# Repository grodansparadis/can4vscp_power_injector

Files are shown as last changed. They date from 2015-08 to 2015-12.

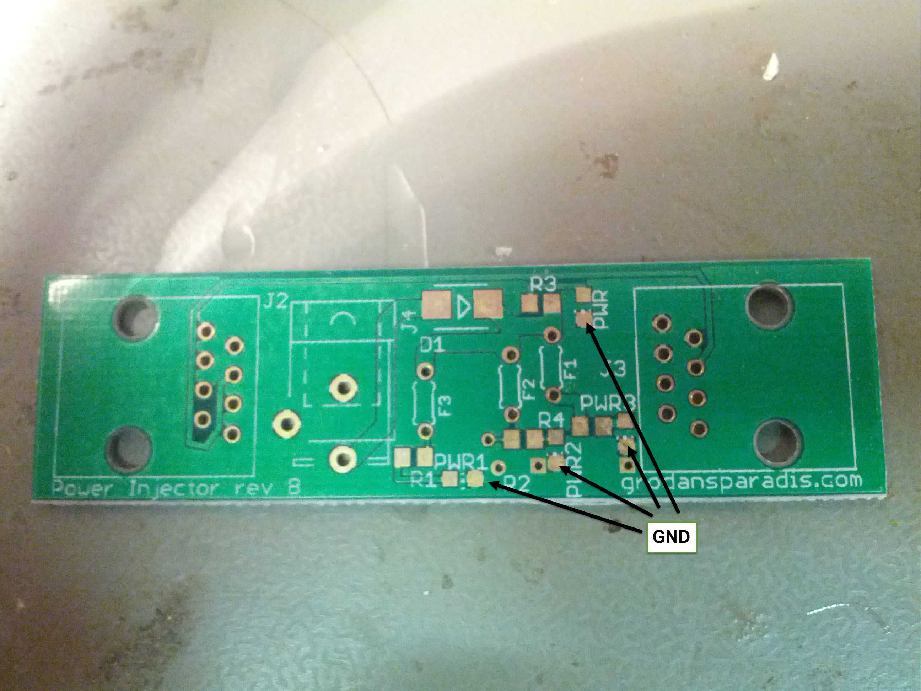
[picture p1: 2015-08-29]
docs/markers_gnd.jpg

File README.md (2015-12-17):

<h1>Power injector module for CAN4VSCP</h1>



With the power injector you can power the CAN4VSCP bus and also power up to 16 CAN4VSCP modules using the daisy chain connector. This is a perfect companion board to use when you need to connect a number of CAN4VSCP boards in a cabinet and then connect them to thw world.

It also have two 120 ohm terminations that can be activated if needed.

It is also possible to get the module with a resettable fuse that allow a maximum of 500 mA for all modules connected to the board. The fuse will trip at about 800 mA. This can be a good safety precaution for wired networks. 

<hr>

This project is part of the <a href="http://www.vscp.org">VSCP (Very Simple Control Protocol) project</a>. 

<hr>

This project is licensed under the 
<a href="http://creativecommons.org/licenses/by-nc-sa/3.0/">Creative Commons open source license Attribution-NonCommercial-ShareAlike 3.0 Unported</a>. 
Other license options are available by conacting <a href="malto:info@grodansparadis.com">Paradis of the Frog AB</a>

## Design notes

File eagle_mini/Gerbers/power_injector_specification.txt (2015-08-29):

Ake Hedman
Grodans Paradis AB

Date:				2014-06-18
Part Number: 		Power Injector
Number of boards: 	120
Number of layers: 	2 
Material: 			FR4
Final Thickness:	1.6 mm
Final copper:		1/1oz
Surface treatment: 	ENIG
Unit Size:			72 x 20 mm
Panel Size:		
Unit/panel:			12
Solder Mask:		Green
Silk Screen: 		White	
Outline Profile:	CNC Routing + V-cut
X-out Allowed:		1
Stencil needed:		no

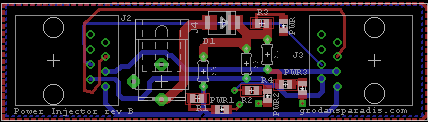
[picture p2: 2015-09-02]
eagle_mini/power_injector_mini_rev_b_brd.png

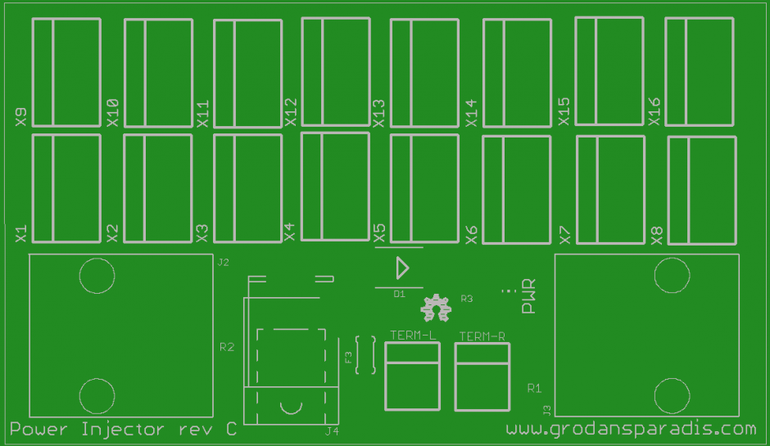
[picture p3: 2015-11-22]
eagle_big/Gerbers/power_injector_rev_c_gto_small.png

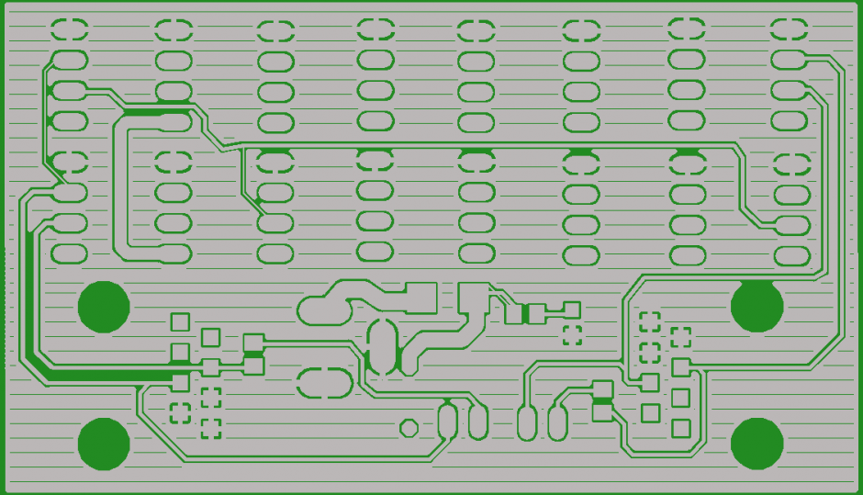
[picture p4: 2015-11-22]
eagle_big/Gerbers/power_injector_rev_c_gtl_small.png

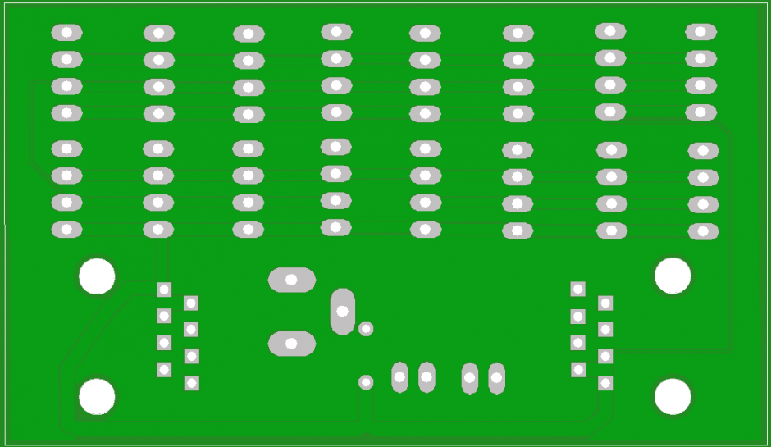
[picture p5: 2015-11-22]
eagle_big/Gerbers/power_injector_rev_c_bottom_small.png

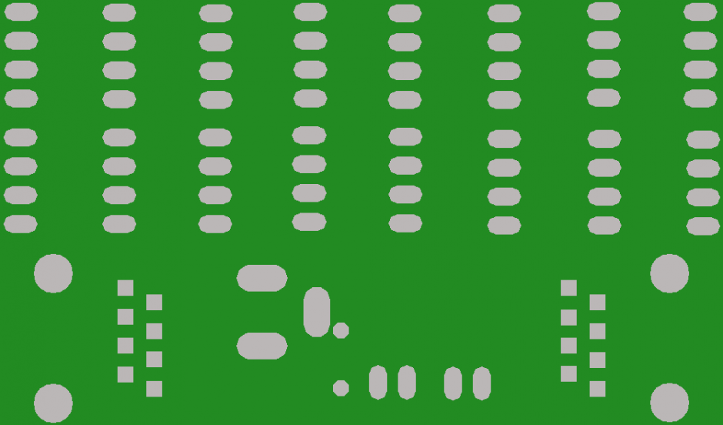
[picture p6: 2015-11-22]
eagle_big/Gerbers/power_injector_rev_c_gbs_small.png

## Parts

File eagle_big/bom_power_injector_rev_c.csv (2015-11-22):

Part | Value | Device | Package | Description | MF | MPN | OC_FARNELL | OC_NEWARK
D1 | PMEG3015EH,115 | DIODE-SMB | SMB | DIODE
F3 | MF-R050 | R-EU_0204/5 | 0204/5 | RESISTOR, European symbol
J2 | A00-108-220-450 | A00-108-220-450 | RJ-45
J3 | A00-108-220-450 | A00-108-220-450 | RJ-45
J4 |  | JACK-PLUG0 | SPC4077 | DC POWER JACK |  |  | unknown | unknown
LED1 |  | LEDCHIP-LED0805 | CHIP-LED0805 | LED
R1 | 120 | R-EU_R0805 | R0805 | RESISTOR, European symbol
R2 | 120 | R-EU_R0805 | R0805 | RESISTOR, European symbol
R3 | 4k7 | R-EU_R0805 | R0805 | RESISTOR, European symbol
TERM-L | 22-23-2021 | 22-23-2021 | 22-23-2021 | .100 (2.54mm) Center Header - 2 Pin" | MOLEX | 22-23-2021 | 1462926 | 25C3832
TERM-R | 22-23-2021 | 22-23-2021 | 22-23-2021 | .100 (2.54mm) Center Header - 2 Pin" | MOLEX | 22-23-2021 | 1462926 | 25C3832
X1 | 22-23-2041 | 22-23-2041 | 22-23-2041 | .100 (2.54mm) Center Header - 4 Pin" | MOLEX | 22-23-2041 | 1462920 | 38C0355
X2 | 22-23-2041 | 22-23-2041 | 22-23-2041 | .100 (2.54mm) Center Header - 4 Pin" | MOLEX | 22-23-2041 | 1462920 | 38C0355
X3 | 22-23-2041 | 22-23-2041 | 22-23-2041 | .100 (2.54mm) Center Header - 4 Pin" | MOLEX | 22-23-2041 | 1462920 | 38C0355
X4 | 22-23-2041 | 22-23-2041 | 22-23-2041 | .100 (2.54mm) Center Header - 4 Pin" | MOLEX | 22-23-2041 | 1462920 | 38C0355
X5 | 22-23-2041 | 22-23-2041 | 22-23-2041 | .100 (2.54mm) Center Header - 4 Pin" | MOLEX | 22-23-2041 | 1462920 | 38C0355
X6 | 22-23-2041 | 22-23-2041 | 22-23-2041 | .100 (2.54mm) Center Header - 4 Pin" | MOLEX | 22-23-2041 | 1462920 | 38C0355
X7 | 22-23-2041 | 22-23-2041 | 22-23-2041 | .100 (2.54mm) Center Header - 4 Pin" | MOLEX | 22-23-2041 | 1462920 | 38C0355
X8 | 22-23-2041 | 22-23-2041 | 22-23-2041 | .100 (2.54mm) Center Header - 4 Pin" | MOLEX | 22-23-2041 | 1462920 | 38C0355
X9 | 22-23-2041 | 22-23-2041 | 22-23-2041 | .100 (2.54mm) Center Header - 4 Pin" | MOLEX | 22-23-2041 | 1462920 | 38C0355
X10 | 22-23-2041 | 22-23-2041 | 22-23-2041 | .100 (2.54mm) Center Header - 4 Pin" | MOLEX | 22-23-2041 | 1462920 | 38C0355
X11 | 22-23-2041 | 22-23-2041 | 22-23-2041 | .100 (2.54mm) Center Header - 4 Pin" | MOLEX | 22-23-2041 | 1462920 | 38C0355
X12 | 22-23-2041 | 22-23-2041 | 22-23-2041 | .100 (2.54mm) Center Header - 4 Pin" | MOLEX | 22-23-2041 | 1462920 | 38C0355
X13 | 22-23-2041 | 22-23-2041 | 22-23-2041 | .100 (2.54mm) Center Header - 4 Pin" | MOLEX | 22-23-2041 | 1462920 | 38C0355
X14 | 22-23-2041 | 22-23-2041 | 22-23-2041 | .100 (2.54mm) Center Header - 4 Pin" | MOLEX | 22-23-2041 | 1462920 | 38C0355
X15 | 22-23-2041 | 22-23-2041 | 22-23-2041 | .100 (2.54mm) Center Header - 4 Pin" | MOLEX | 22-23-2041 | 1462920 | 38C0355
X16 | 22-23-2041 | 22-23-2041 | 22-23-2041 | .100 (2.54mm) Center Header - 4 Pin" | MOLEX | 22-23-2041 | 1462920 | 38C0355

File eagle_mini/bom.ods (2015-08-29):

Partl | ist exported fro | m C:/Users/akhe/Do | cuments/dev | elopment/hardware_zeus/can | 4vscp/power_inje | ctor/eagle/power_injector_r | ev_a.sch at 2011-10-03 | 11:50:20
Part | Value | Device Pa | ckage | Description | Description | Supplier Partnumber | Price
D1 | PMEG3015EH,115 | DIODE-SMB SM | B | DIODE | Protection diod | Digikey 568-4127-1-ND | 3,84
F1 | MF-R050 | R-EU_M0805 M0 | 805 | RESISTOR, European symbol | Fuse | Digikey MF-r050-nd | 6,24
F2 | MF-R050 | R-EU_M0805 M0 | 805 | RESISTOR, European symbol | Fuse | Digikey MF-r050-nd | 6,24
F3 | MF-R050 | R-EU_M0805 M0 | 805 | RESISTOR, European symbol | Fuse | Digikey MF-r050-nd | 6,24
J1 |  | JACK-PLUG0 SP | C4077 | DC POWER JACK | Power connector | Digikey CP-102A-ND | 7,36
J2 | A00-108-220-450 | A00-108-220-450 RJ | -45 |  | RJ-45 connector | Digikey 151-1099-nd | 5,6
J3 | A00-108-220-450 | A00-108-220-450 RJ | -45 |  | RJ-45 connector | Digikey 151-1099-nd | 5,6
LED1 |  | LEDCHIP-LED0805 CH | IP-LED0805 | LED | Green LED | Digikey 475-1410-1-nd | 0,88
LED2 |  | LEDCHIP-LED0805 CH | IP-LED0805 | LED | Green LED | Digikey 475-1410-1-nd | 0,88
LED3 |  | LEDCHIP-LED0805 CH | IP-LED0805 | LED | Green LED | Digikey 475-1410-1-nd | 0,88
LED4 |  | LEDCHIP-LED0805 CH | IP-LED0805 | LED | Green LED | Digikey 475-1410-1-nd | 0,88
R1 | 4k7 | R-EU_R0805 R0 | 805 | RESISTOR, European symbol | Resistor | Bejoken 454668 | 0,01
R2 | 4k7 | R-EU_R0805 R0 | 805 | RESISTOR, European symbol | Resistor | Bejoken 454668 | 0,01
R3 | 4k7 | R-EU_R0805 R0 | 805 | RESISTOR, European symbol | Resistor | Bejoken 454668 | 0,01
R4 | 4k7 | R-EU_R0805 R0 | 805 | RESISTOR, European symbol | Resistor | Bejoken 454668 | 0,01
 |  |  |  |  |  |  | 44,68

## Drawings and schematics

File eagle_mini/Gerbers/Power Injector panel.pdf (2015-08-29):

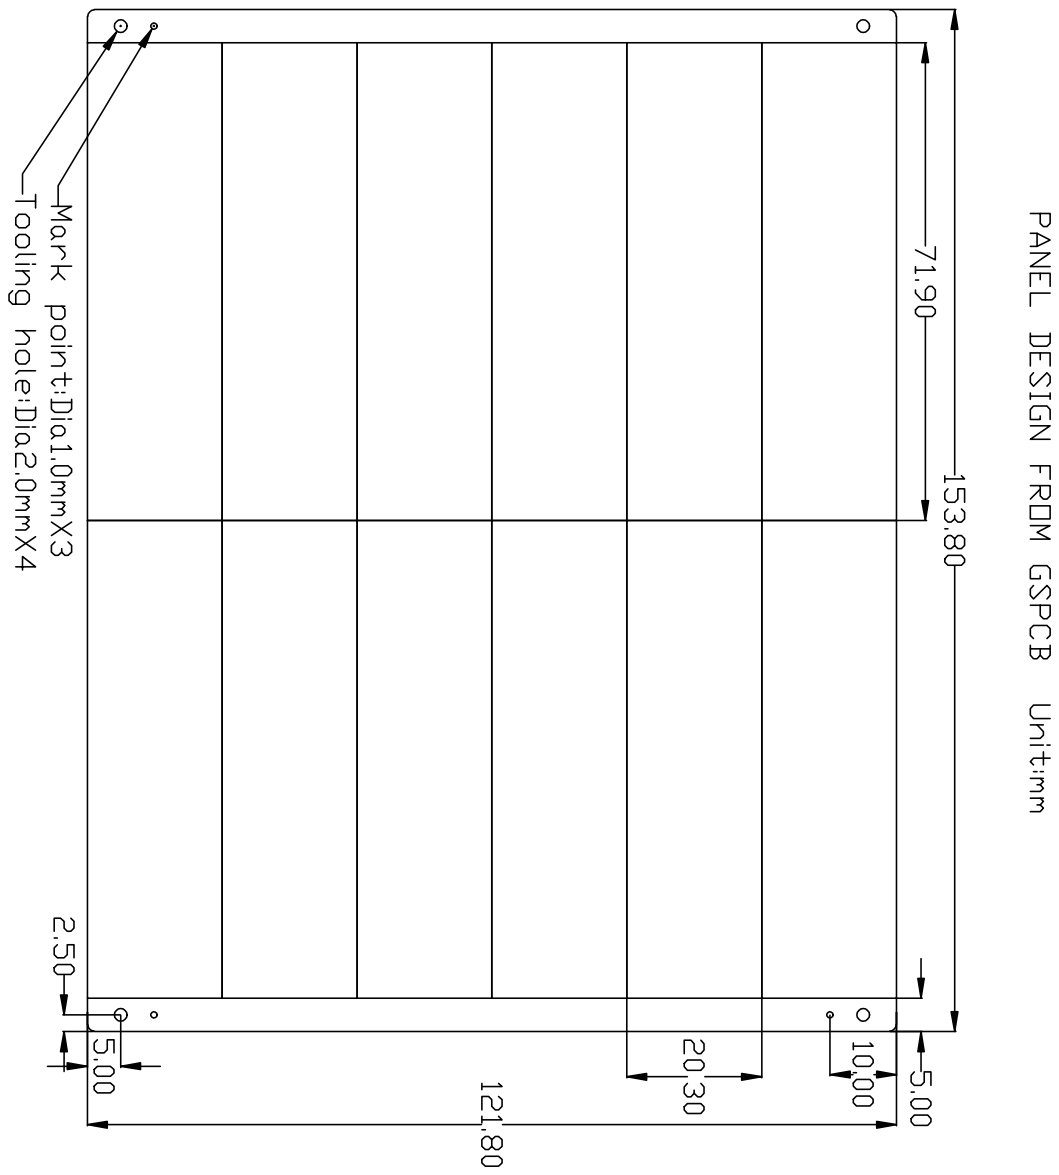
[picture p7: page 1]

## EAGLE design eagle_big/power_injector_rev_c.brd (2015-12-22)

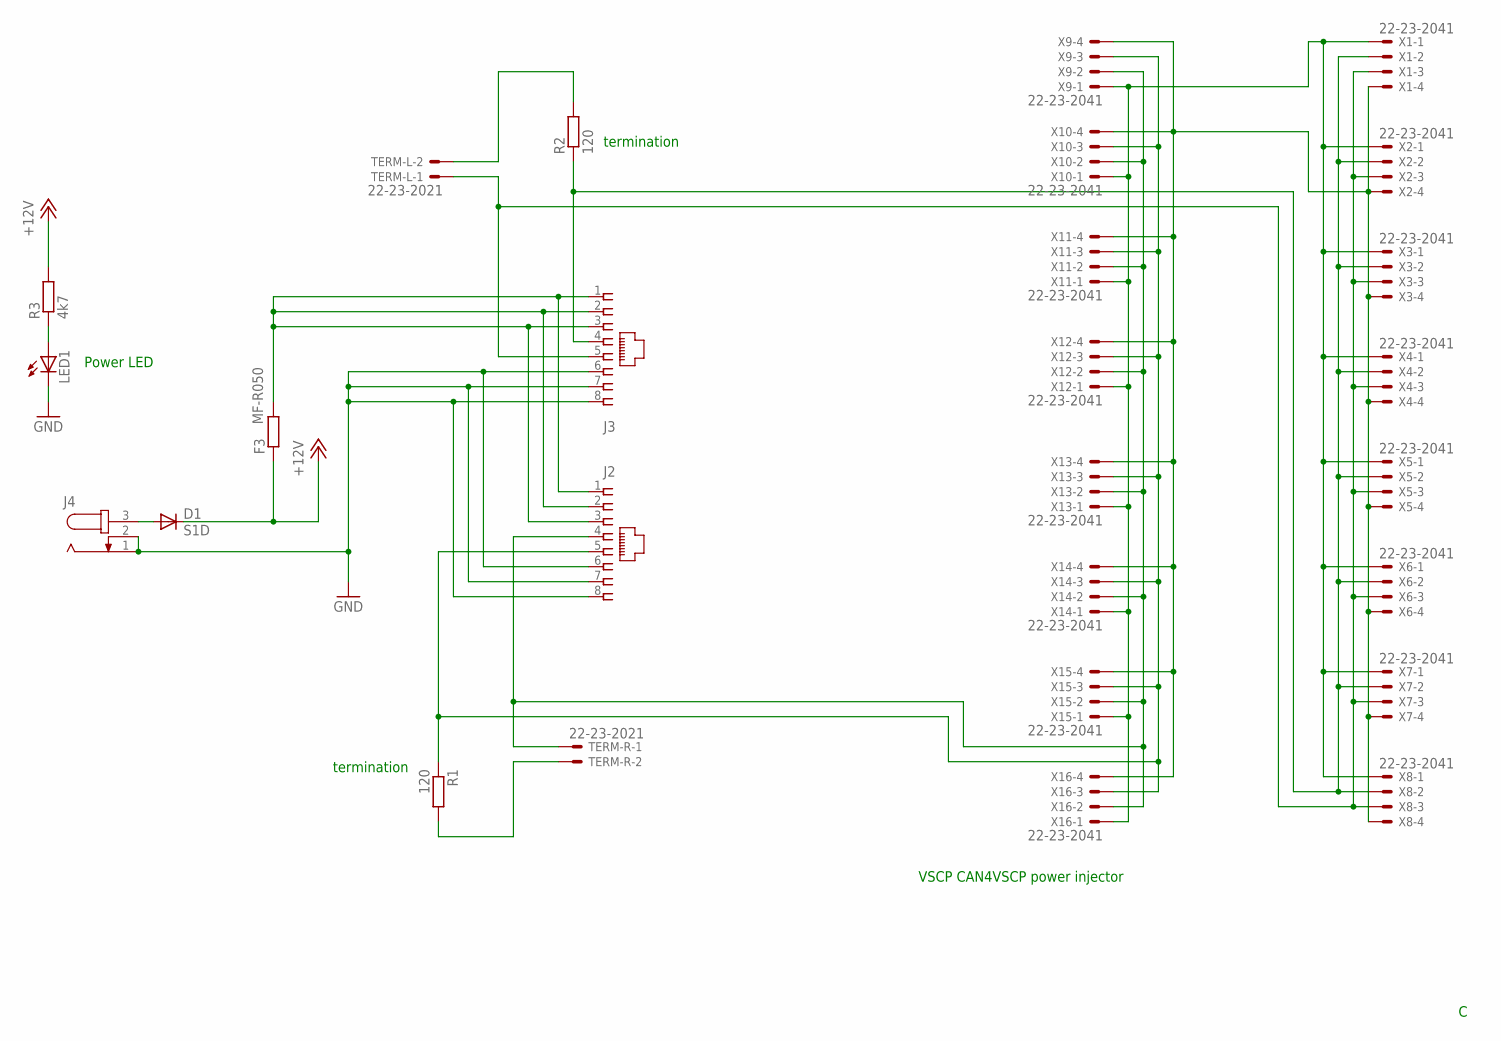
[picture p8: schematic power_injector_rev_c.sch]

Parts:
D1: S1D; SMB
F3: MF-R050; 0204/5
J2, J3: A00-108-220-450; RJ-45
J4: JACK-PLUG0; SPC4077
LED1: LEDCHIP-LED0805; CHIP-LED0805
R1, R2: 120; R0805
R3: 4k7; R0805
TERM-L: 22-23-2021
TERM-R: 22-23-2021
X1, X2, X3, X4, X5, X6, X7, X8, X9, X10, X11, X12, X13, X14, X15, X16: 22-23-2041

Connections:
+12V: D1.C, F3.1, R3.2
CANH: J2.4, J3.4, R2.1, TERM-R.1, X1.2, X2.2, X3.2, X4.2, X5.2, X6.2, X7.2, X8.2, X9.2, X10.2, X11.2, X12.2, X13.2, X14.2, X15.2, X16.2
CANL: J2.5, J3.5, R1.1, TERM-L.1, X1.3, X2.3, X3.3, X4.3, X5.3, X6.3, X7.3, X8.3, X9.3, X10.3, X11.3, X12.3, X13.3, X14.3, X15.3, X16.3
GND: J2.6, J2.7, J2.8, J3.6, J3.7, J3.8, J4.1, J4.2, LED1.C, X1.4, X2.4, X3.4, X4.4, X5.4, X6.4, X7.4, X8.4, X9.4, X10.4, X11.4, X12.4, X13.4, X14.4, X15.4, X16.4
unnamed: LED1.A, R3.1
unnamed: R1.2, TERM-R.2
unnamed: D1.A, J4.3
unnamed: R2.2, TERM-L.2
POWER: F3.2, J2.1, J2.2, J2.3, J3.1, J3.2, J3.3, X1.1, X2.1, X3.1, X4.1, X5.1, X6.1, X7.1, X8.1, X9.1, X10.1, X11.1, X12.1, X13.1, X14.1, X15.1, X16.1

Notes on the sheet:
Power LED
VSCP CAN4VSCP power injector
termination

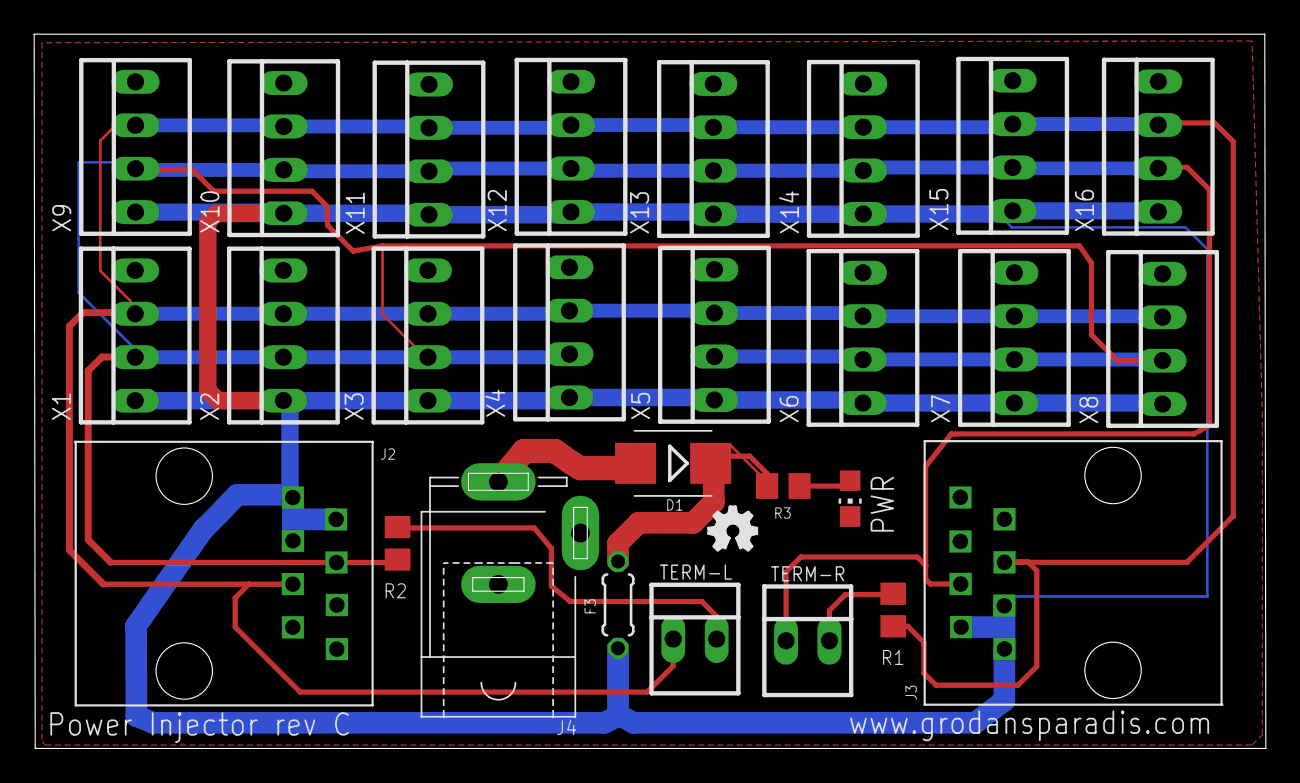
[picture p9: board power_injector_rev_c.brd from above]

Board: 2 copper layers, 72.1 x 41.8 mm, 28 parts (0 on the bottom side), 9 nets.

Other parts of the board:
U$1: OSHW_FILLX100_NOTEXT

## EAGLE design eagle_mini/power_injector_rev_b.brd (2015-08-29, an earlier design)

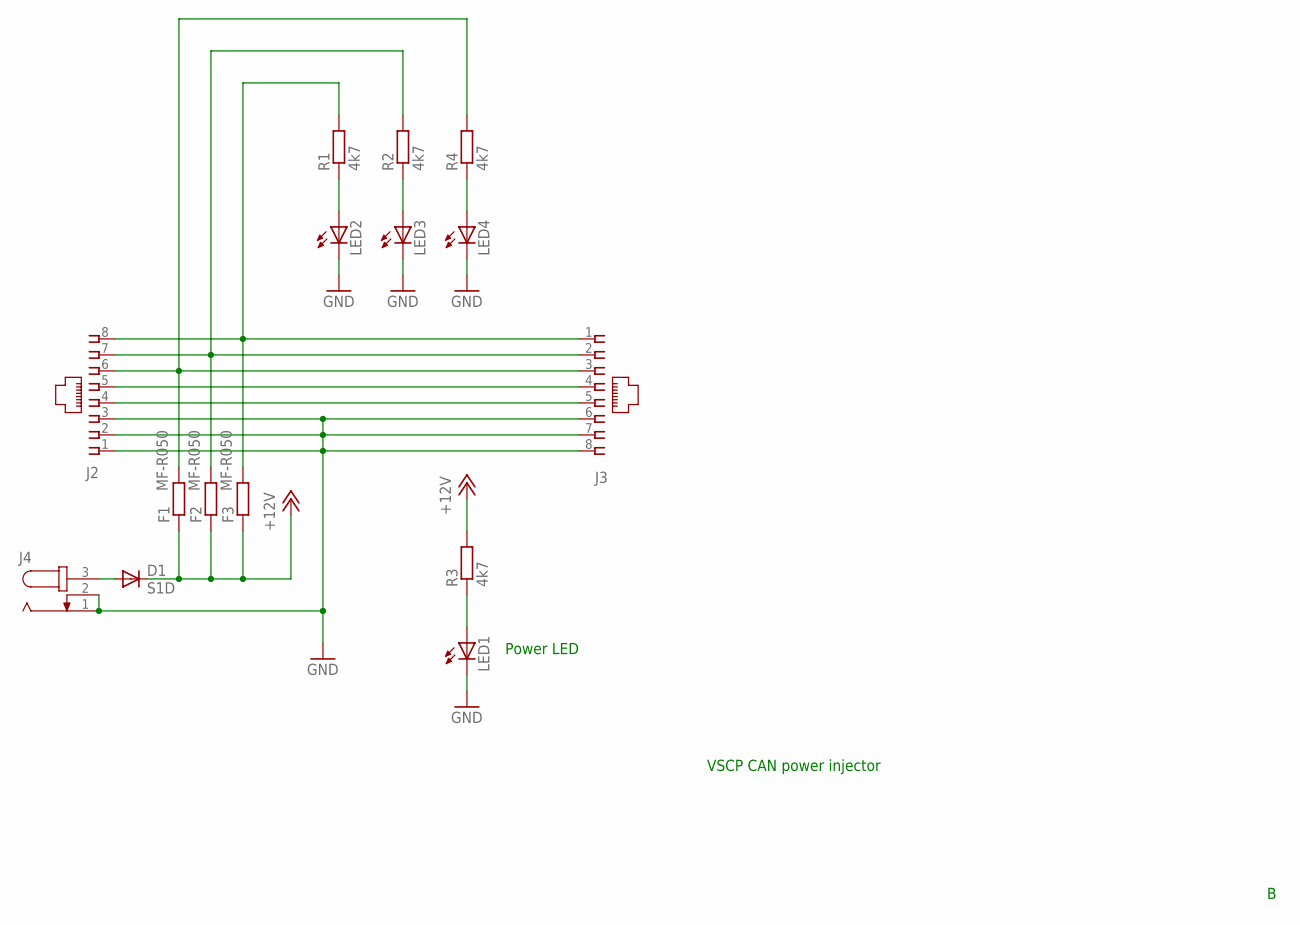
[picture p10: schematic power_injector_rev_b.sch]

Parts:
D1: S1D; SMB
F1, F2, F3: MF-R050; 0204/5
J2, J3: A00-108-220-450; RJ-45
J4: JACK-PLUG0; SPC4077
LED1, LED2, LED3, LED4: LEDCHIP-LED0805; CHIP-LED0805
R1, R2, R3, R4: 4k7; R0805

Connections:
+12V: D1.C, F1.1, F2.1, F3.1, R3.2
GND: J2.1, J2.2, J2.3, J3.6, J3.7, J3.8, J4.1, J4.2, LED1.C, LED2.C, LED3.C, LED4.C
unnamed: LED3.A, R2.1
unnamed: LED1.A, R3.1
unnamed: J2.5, J3.4
unnamed: J2.4, J3.5
unnamed: LED4.A, R4.1
unnamed: LED2.A, R1.1
unnamed: D1.A, J4.3
PWR1: F3.2, J2.8, J3.1, R1.2
PWR2: F2.2, J2.7, J3.2, R2.2
PWR3: F1.2, J2.6, J3.3, R4.2

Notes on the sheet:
Power LED
VSCP CAN power injector

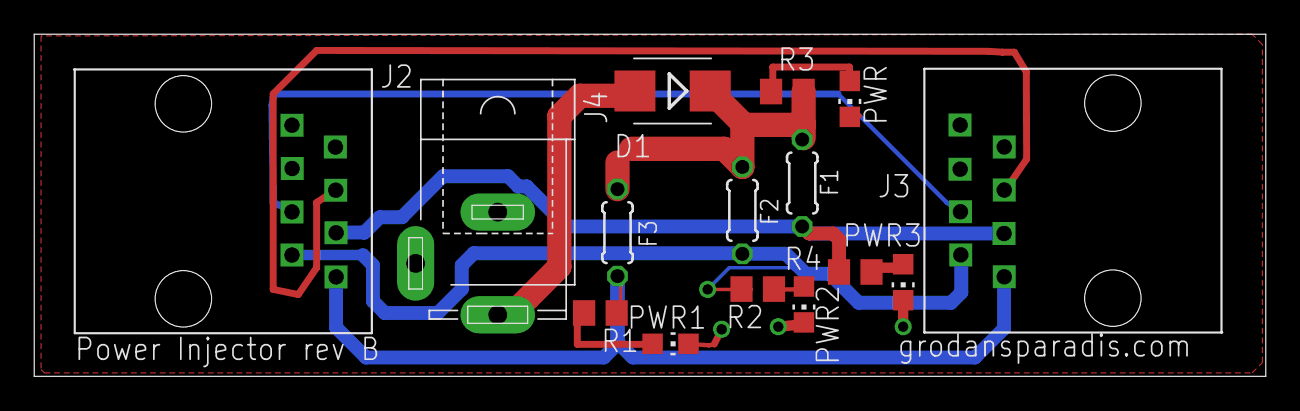
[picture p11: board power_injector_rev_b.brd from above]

Board: 2 copper layers, 72.0 x 20.0 mm, 15 parts (0 on the bottom side), 12 nets.

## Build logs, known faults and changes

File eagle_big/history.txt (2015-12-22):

History file for big power injector
===================================

2015-12-22 AKHE - Named D1
2015-09-28 AKHE - Added terminators.
2015-09-28 AKHE - CAN/CANH now goes through connectors in sequence.

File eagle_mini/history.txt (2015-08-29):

CAN4VSCP Power injector
=======================

2015-08-26 - AKHE - tidied up
2014-06-14 - AKHE - Changed input diod to PMEG3015EH,115 - http://www.digikey.com/product-detail/en/PMEG3015EH,115/568-4127-1-ND/1589942
2014-11-24 - AKHE - Wring wiring between RJ45's fixed.
2014-11-24 - AKHE - Rev C
2014-06-18 - AKHE - Fixing dimensions
2014-06-18 - AKHE - Job sent out
2012-01-20 - AKHE - Changed power connector with one with 1.1mm holes.
2012-01-20 - AKHE - Rev B Wrong footprint for F1, F2, F3 corrected.
2012-01-20 - AKHE - Rev B

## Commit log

2015-08-29 Added new design
    [bom.ods, power_injector_rev_a.brd, power_injector_rev_a.sch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]
2015-09-02 Added board and schema pictures
2015-09-28 Added terminators and changed connection sequence
    [power_injector_rev_a.brd, power_injector_rev_a.sch]
2015-11-22 Edit + bom added + gerbers
    [bom_power_injector_rev_c.csv, power_injector_rev_c.brd, power_injector_rev_c.sch]
2015-12-22 Named D1
    [power_injector_rev_c.brd, power_injector_rev_c.sch]
